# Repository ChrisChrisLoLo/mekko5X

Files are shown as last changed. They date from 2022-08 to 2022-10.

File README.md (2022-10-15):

# mekko5X

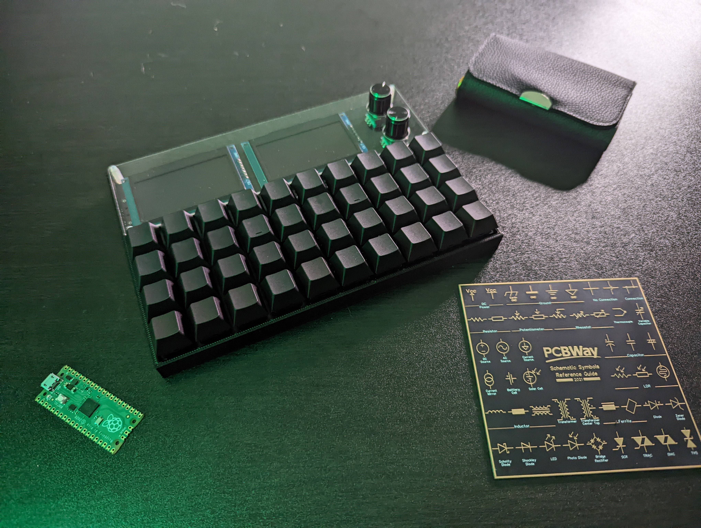
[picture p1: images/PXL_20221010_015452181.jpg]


Part cyberdeck, part ortholinear. With 2 knobs and 2 large OLED displays, this keyboard can be used for animations, displaying information, or for controlling a GUI. The small form factor makes the board a unique ortholinear keyboard, or a powerful macropad. It could also double as a MIDI controller!

Powered by a Raspberry Pi Pico, this keyboard should have more than enough space and power for any kind of firmware you have in mind!

## Status
Pre-prototyping phase. Playing around with setting up the OLED drivers, and will look into how to get it working with QMK. Testing pending. Copy and build if you're sure you know what you're doing. BYO firmware.

## Features
- 2 Rotary encoders
- 2 Oled displays on a SPI bus
- 4x10 matrix
- Powered by an RP2040

## Acknowledgements
Big thank you to [PCBWay](https://www.pcbway.com/) for greenlighting and sponsoring a project such as this! Overtime, I've come to appretiate the quality of the silkscreen and soldermask boards I get from PCBWay, and would strongly consider them if I had to sell or give a quality PCB to a friend or and customer. PCBWay has also given back to the community by supporting projects like these, so I strongly recommend them if you're looking to make a board for yourself!

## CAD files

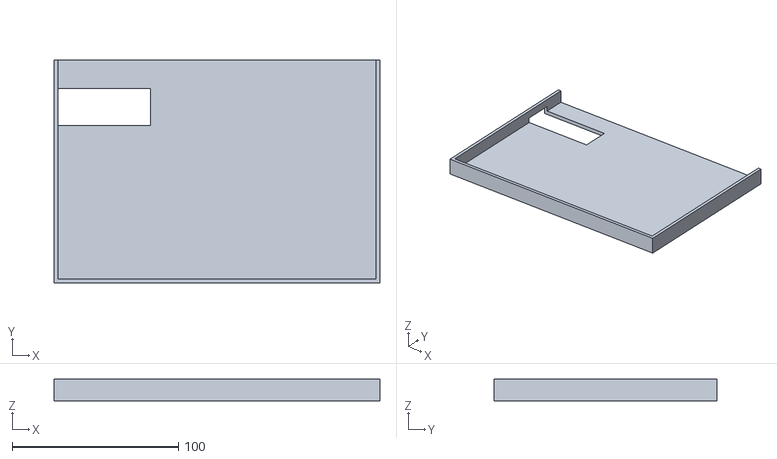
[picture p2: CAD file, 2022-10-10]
case/case_prototype.stl
196.1 x 134.1 x 13.0

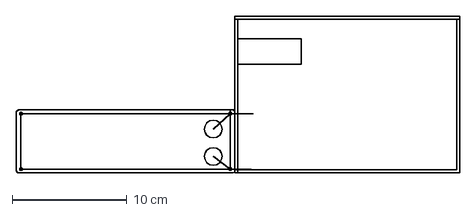
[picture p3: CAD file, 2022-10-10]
outlines/mekko5X v4.dxf
38.7 x 13.7 cm

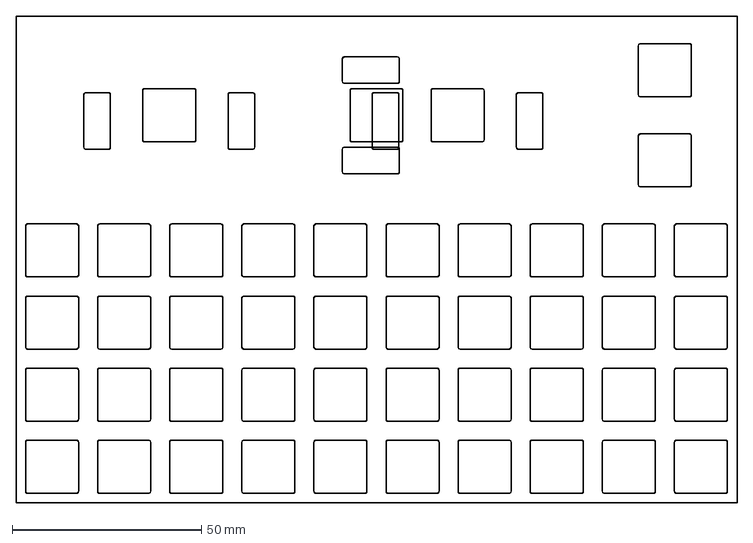
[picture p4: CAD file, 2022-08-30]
outlines/plate-2022-08-30T16 42 45.877Z.dxf
190.5 x 128.6 mm

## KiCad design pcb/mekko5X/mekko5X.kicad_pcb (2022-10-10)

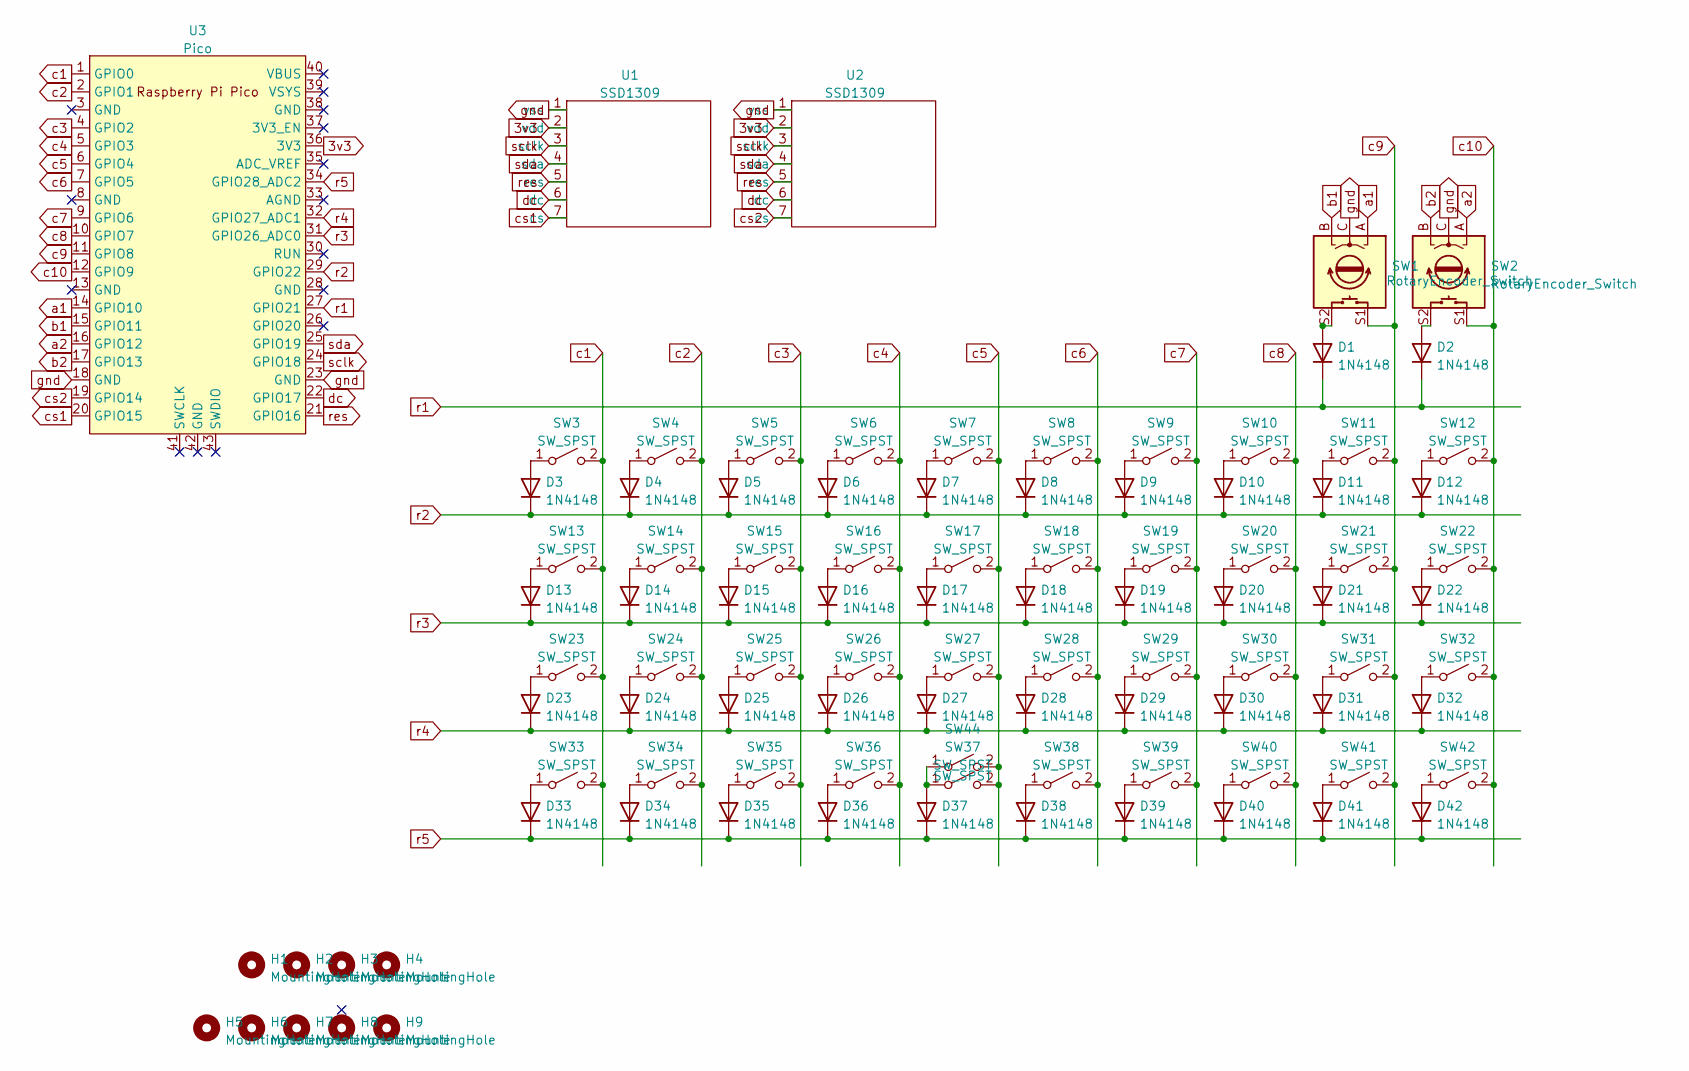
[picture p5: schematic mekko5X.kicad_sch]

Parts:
D1, D2, D3, D4, D5, D6, D7, D8, D9, D10, D11, D12, D13, D14, D15, D16, D17, D18, D19, D20, D21, D22, D23, D24, D25, D26, D27, D28, D29, D30, D31, D32, D33, D34, D35, D36, D37, D38, D39, D40, D41, D42: 1N4148
H1, H2, H3, H4, H5, H6, H7, H8, H9: MountingHole; MountingHole_2.2mm_M2_DIN965
SW1, SW2: RotaryEncoder_Switch; RotaryEncoder_Alps_EC11E-Switch_Vertical_H20mm
SW3, SW4, SW5, SW6, SW7, SW8, SW9, SW10, SW11, SW12, SW13, SW14, SW15, SW16, SW17, SW18, SW19, SW20, SW21, SW22, SW23, SW24, SW25, SW26, SW27, SW28, SW29, SW30, SW31, SW32, SW33, SW34, SW35, SW36, SW37, SW38, SW39, SW40, SW41, SW42, SW44: SW_SPST; Kailh_socket_MX
U1, U2: SSD1309; 2.4_inch_OLED
U3: Pico; RPi_Pico_SMD_TH

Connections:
3v3: U1.2 (vdd), U2.2 (vdd), U3.36 (3V3)
unnamed: D1.2 (A), SW1.S2
unnamed: D2.2 (A), SW2.S2
unnamed: D3.2 (A), SW3.1 (A)
unnamed: D4.2 (A), SW4.1 (A)
unnamed: D5.2 (A), SW5.1 (A)
unnamed: D6.2 (A), SW6.1 (A)
unnamed: D7.2 (A), SW7.1 (A)
unnamed: D8.2 (A), SW8.1 (A)
unnamed: D9.2 (A), SW9.1 (A)
unnamed: D10.2 (A), SW10.1 (A)
unnamed: D11.2 (A), SW11.1 (A)
unnamed: D12.2 (A), SW12.1 (A)
unnamed: D13.2 (A), SW13.1 (A)
unnamed: D14.2 (A), SW14.1 (A)
unnamed: D15.2 (A), SW15.1 (A)
unnamed: D16.2 (A), SW16.1 (A)
unnamed: D17.2 (A), SW17.1 (A)
unnamed: D18.2 (A), SW18.1 (A)
unnamed: D19.2 (A), SW19.1 (A)
unnamed: D20.2 (A), SW20.1 (A)
unnamed: D21.2 (A), SW21.1 (A)
unnamed: D22.2 (A), SW22.1 (A)
unnamed: D23.2 (A), SW23.1 (A)
unnamed: D24.2 (A), SW24.1 (A)
unnamed: D25.2 (A), SW25.1 (A)
unnamed: D26.2 (A), SW26.1 (A)
unnamed: D27.2 (A), SW27.1 (A)
unnamed: D28.2 (A), SW28.1 (A)
unnamed: D29.2 (A), SW29.1 (A)
unnamed: D30.2 (A), SW30.1 (A)
unnamed: D31.2 (A), SW31.1 (A)
unnamed: D32.2 (A), SW32.1 (A)
unnamed: D33.2 (A), SW33.1 (A)
unnamed: D34.2 (A), SW34.1 (A)
unnamed: D35.2 (A), SW35.1 (A)
unnamed: D36.2 (A), SW36.1 (A)
unnamed: D37.2 (A), SW37.1 (A), SW44.1 (A)
unnamed: D38.2 (A), SW38.1 (A)
unnamed: D39.2 (A), SW39.1 (A)
unnamed: D40.2 (A), SW40.1 (A)
unnamed: D41.2 (A), SW41.1 (A)
unnamed: D42.2 (A), SW42.1 (A)
a1: SW1.A, U3.14 (GPIO10)
a2: SW2.A, U3.16 (GPIO12)
b1: SW1.B, U3.15 (GPIO11)
b2: SW2.B, U3.17 (GPIO13)
c1: SW3.2 (B), SW13.2 (B), SW23.2 (B), SW33.2 (B), U3.1 (GPIO0)
c2: SW4.2 (B), SW14.2 (B), SW24.2 (B), SW34.2 (B), U3.2 (GPIO1)
c3: SW5.2 (B), SW15.2 (B), SW25.2 (B), SW35.2 (B), U3.4 (GPIO2)
c4: SW6.2 (B), SW16.2 (B), SW26.2 (B), SW36.2 (B), U3.5 (GPIO3)
c5: SW7.2 (B), SW17.2 (B), SW27.2 (B), SW37.2 (B), SW44.2 (B), U3.6 (GPIO4)
c6: SW8.2 (B), SW18.2 (B), SW28.2 (B), SW38.2 (B), U3.7 (GPIO5)
c7: SW9.2 (B), SW19.2 (B), SW29.2 (B), SW39.2 (B), U3.9 (GPIO6)
c8: SW10.2 (B), SW20.2 (B), SW30.2 (B), SW40.2 (B), U3.10 (GPIO7)
c9: SW1.S1, SW11.2 (B), SW21.2 (B), SW31.2 (B), SW41.2 (B), U3.11 (GPIO8)
c10: SW2.S1, SW12.2 (B), SW22.2 (B), SW32.2 (B), SW42.2 (B), U3.12 (GPIO9)
cs1: U1.7 (cs), U3.20 (GPIO15)
cs2: U2.7 (cs), U3.19 (GPIO14)
dc: U1.6 (dc), U2.6 (dc), U3.22 (GPIO17)
gnd: SW1.C, SW2.C, U1.1 (vss), U2.1 (vss), U3.18 (GND), U3.23 (GND)
r1: D1.1 (K), D2.1 (K), U3.27 (GPIO21)
r2: D3.1 (K), D4.1 (K), D5.1 (K), D6.1 (K), D7.1 (K), D8.1 (K), D9.1 (K), D10.1 (K), D11.1 (K), D12.1 (K), U3.29 (GPIO22)
r3: D13.1 (K), D14.1 (K), D15.1 (K), D16.1 (K), D17.1 (K), D18.1 (K), D19.1 (K), D20.1 (K), D21.1 (K), D22.1 (K), U3.31 (GPIO26_ADC0)
r4: D23.1 (K), D24.1 (K), D25.1 (K), D26.1 (K), D27.1 (K), D28.1 (K), D29.1 (K), D30.1 (K), D31.1 (K), D32.1 (K), U3.32 (GPIO27_ADC1)
r5: D33.1 (K), D34.1 (K), D35.1 (K), D36.1 (K), D37.1 (K), D38.1 (K), D39.1 (K), D40.1 (K), D41.1 (K), D42.1 (K), U3.34 (GPIO28_ADC2)
res: U1.5 (res), U2.5 (res), U3.21 (GPIO16)
sclk: U1.3 (sclk), U2.3 (sclk), U3.24 (GPIO18)
sda: U1.4 (sda), U2.4 (sda), U3.25 (GPIO19)

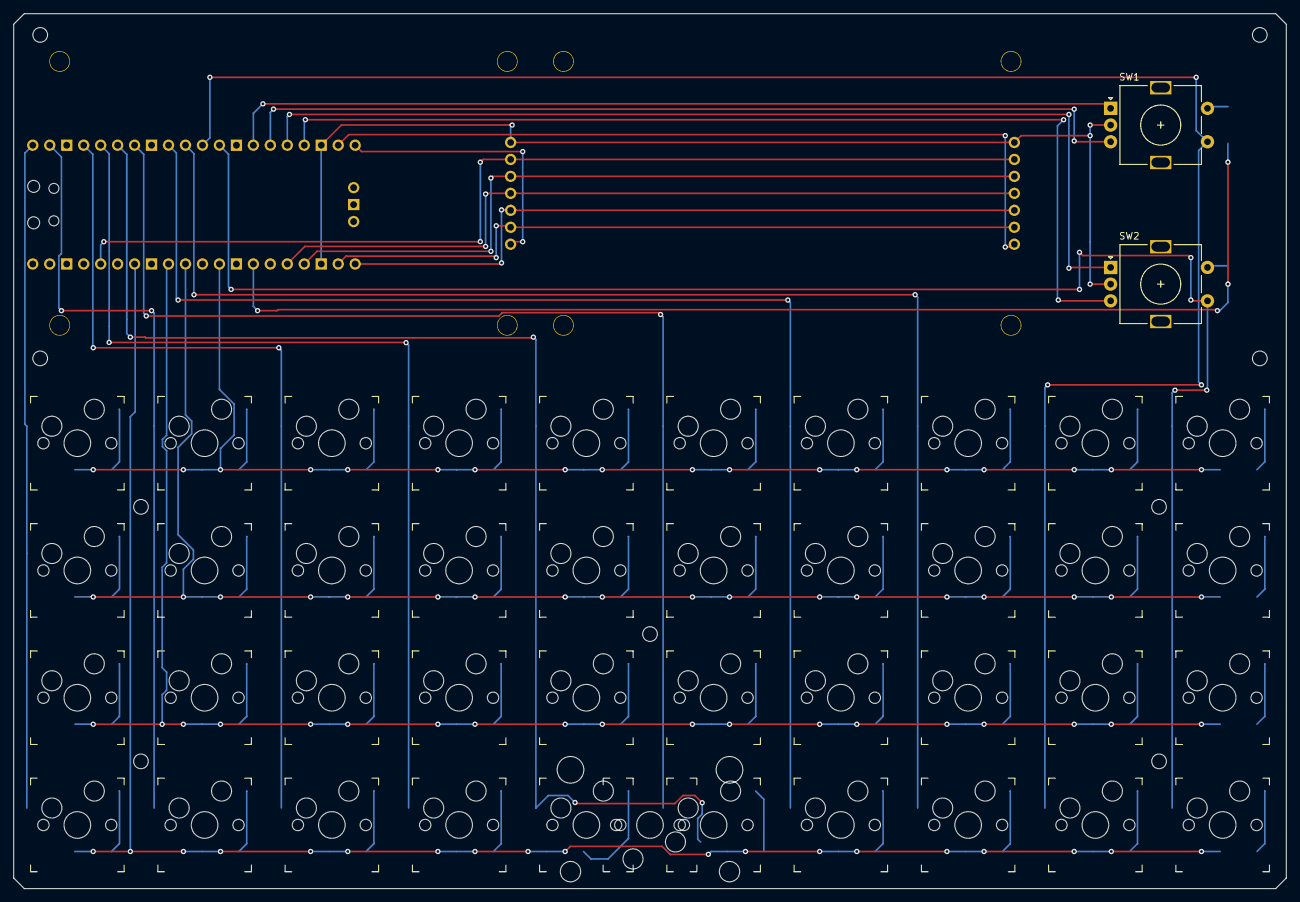
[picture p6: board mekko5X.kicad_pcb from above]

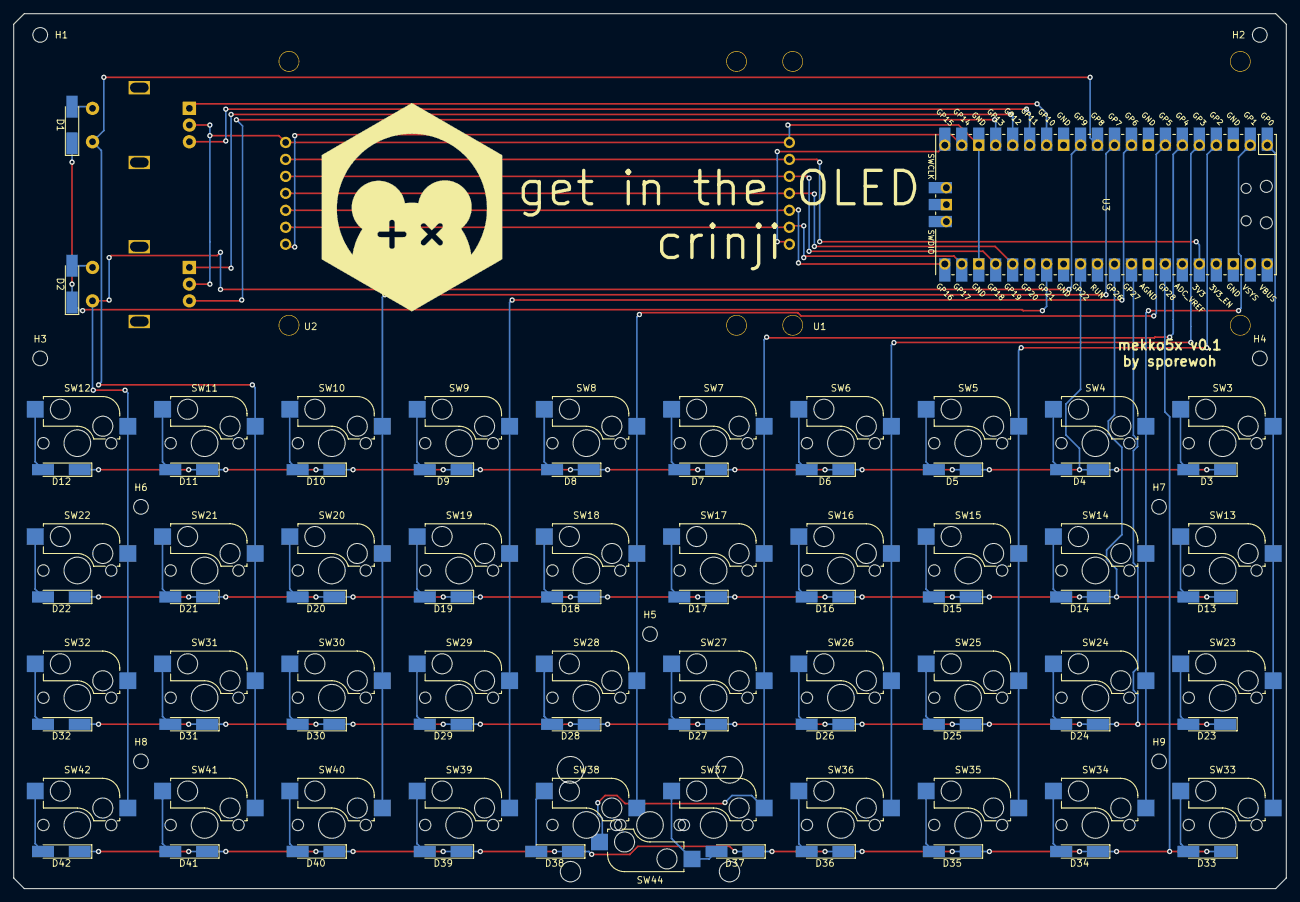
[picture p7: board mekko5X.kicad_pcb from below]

Board: 2 copper layers, 190.5 x 131.0 mm, 97 parts (52 on the bottom side), 69 nets.

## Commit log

2022-08-30 kicad init
    [mekko5X.kicad_pcb, mekko5X.kicad_sch, plate-2022-08-30T16 42 45.877Z.dxf]
2022-09-02 add v0 pcb
    [mekko5X.kicad_pcb]
